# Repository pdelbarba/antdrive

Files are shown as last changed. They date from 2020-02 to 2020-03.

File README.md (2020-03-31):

# Antdrive
Magnettic loop antenna driver arduino shield for amateur radio HF

## Notes
Only one limit switch is pinned out as my setup limits torque such that the capacitor cannot be damaged on the other end. If using standard ethernet cable, you have another two lines (one twisted pair) that can be used for additional switches and signaling however.  I may add this at some point but I'm currently focused on other projects.

## Parts

Designed for the Pololu #1208 stepper motor (https://www.pololu.com/product/1208).  While only rated for 10V it has no issues running at >15v for tuning as the Arduino sketch keeps the motor powered off when not rotating to minimize EMI.  The mounting hardware I used is also available from Pololu.

The motor driver module is an A4988 based board also from Pololu (https://www.pololu.com/product/1182).  In theory it should be able to handle much larger stepper motors, 2A per phase and 35V.

Misc drive hardware is as follows:

https://www.amazon.com/gp/product/B07RXJ5GVG/  Drive side pulley

https://www.amazon.com/gp/product/B07W5L6G8L/  Capacitor side pulley

https://www.amazon.com/gp/product/B07KK86NYX/  Note: I've found these belts to be free of metalic strapping which is important for preventing arcing between the capacitor and the motor

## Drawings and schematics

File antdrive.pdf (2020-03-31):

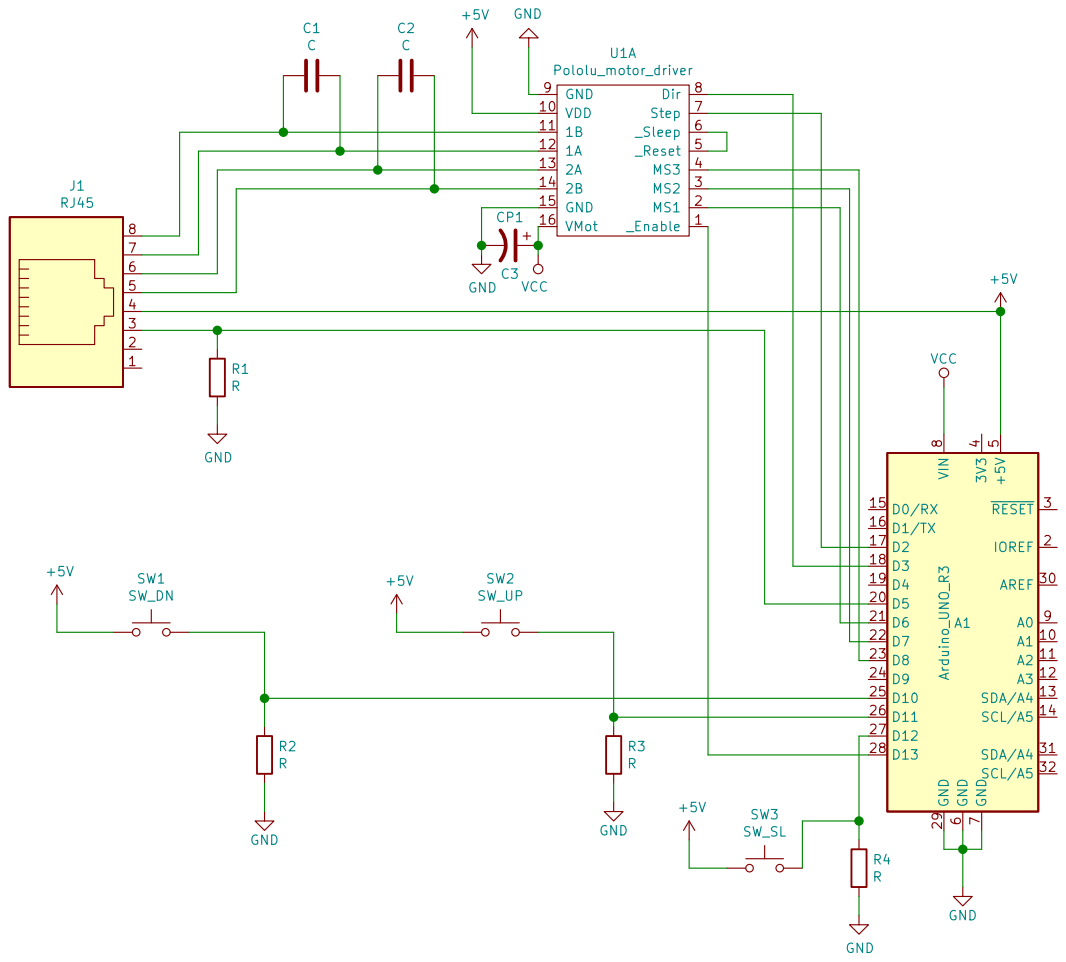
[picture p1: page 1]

Id: 1/1 Title: File: antdrive.sch Sheet: / 12345678

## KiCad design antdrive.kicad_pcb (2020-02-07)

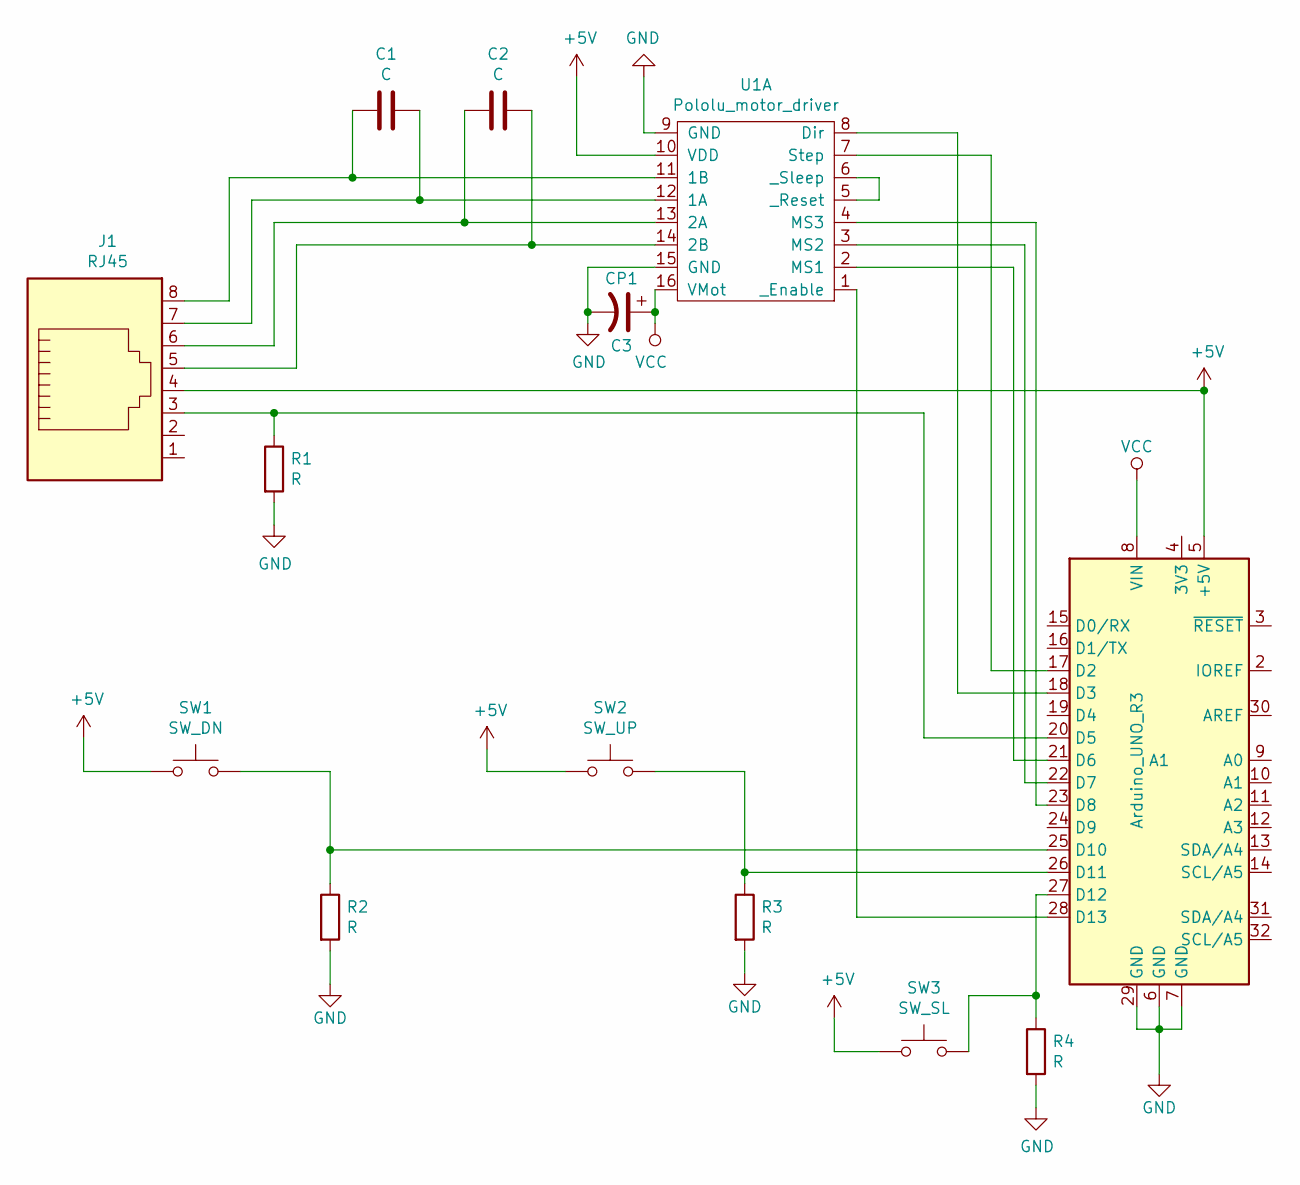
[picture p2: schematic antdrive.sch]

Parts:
A1: Arduino_UNO_R3
C1, C2: C; C_Disc_D5.0mm_W2.5mm_P5.00mm
C3: CP1; CP_Radial_D6.3mm_P2.50mm
J1: RJ45; RJ45_Amphenol_54602-x08_Horizontal
R1, R2, R3, R4: R; R_Axial_DIN0207_L6.3mm_D2.5mm_P10.16mm_Horizontal
SW1: SW_DN; SW_PUSH-12mm
SW2: SW_UP; SW_PUSH-12mm
SW3: SW_SL; SW_PUSH-12mm
U1: Pololu_motor_driver; Pololu_Breakout-16_15.2x20.3mm

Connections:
+5V: A1.5 (+5V), J1.4, SW1.1, SW2.1, SW3.1, U1.10 (VDD)
GND: A1.6 (GND), A1.7 (GND), A1.29 (GND), C3.2, R1.2, R2.2, R3.2, R4.2, U1.9 (GND), U1.15 (GND)
unnamed: A1.17 (D2), U1.7 (Step)
unnamed: A1.18 (D3), U1.8 (Dir)
unnamed: A1.20 (D5), J1.3, R1.1
unnamed: A1.21 (D6), U1.2 (MS1)
unnamed: A1.22 (D7), U1.3 (MS2)
unnamed: A1.23 (D8), U1.4 (MS3)
unnamed: A1.25 (D10), R2.1, SW1.2
unnamed: A1.26 (D11), R3.1, SW2.2
unnamed: A1.27 (D12), R4.1, SW3.2
unnamed: A1.28 (D13), U1.1 (_Enable)
unnamed: C1.1, J1.7, U1.12 (1A)
unnamed: C1.2, J1.8, U1.11 (1B)
unnamed: C2.1, J1.5, U1.14 (2B)
unnamed: C2.2, J1.6, U1.13 (2A)
unnamed: U1.5 (_Reset), U1.6 (_Sleep)
VCC: A1.8 (VIN), C3.1, U1.16 (VMot)

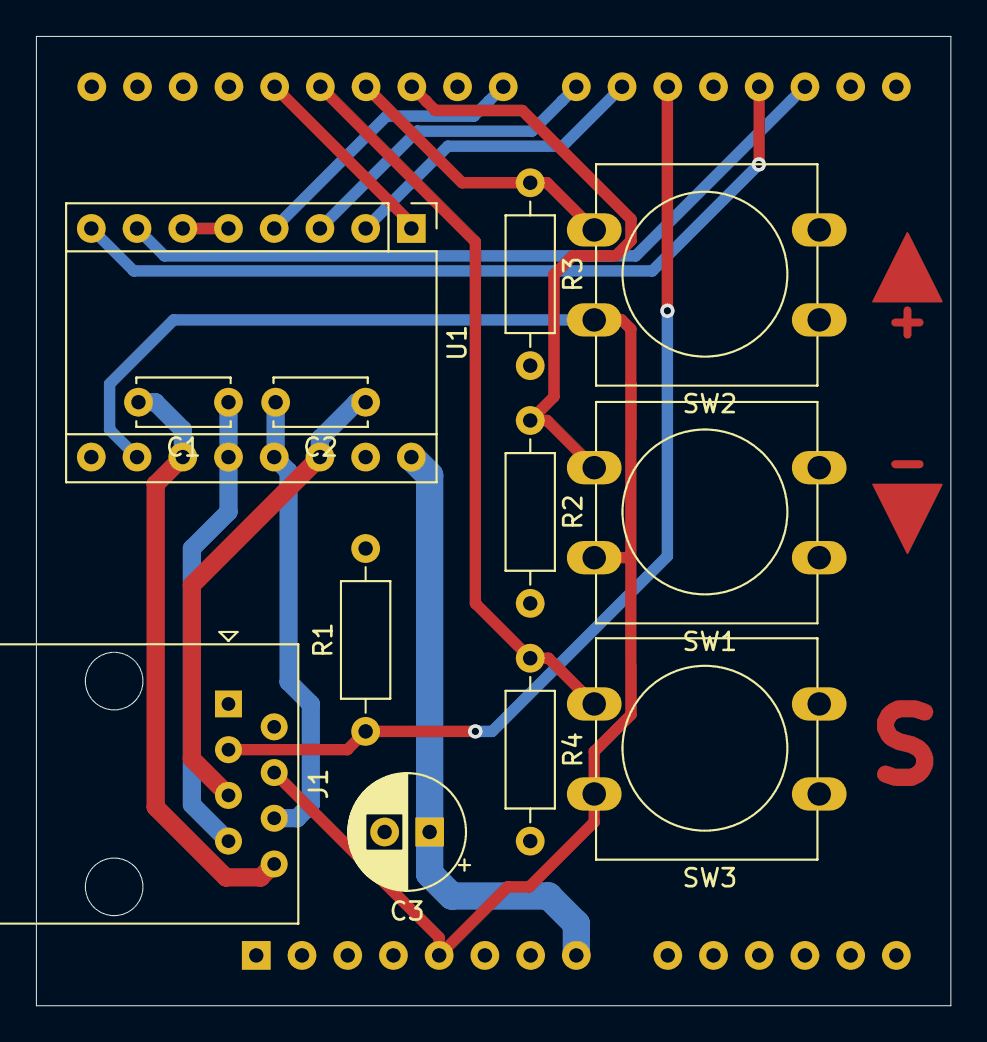
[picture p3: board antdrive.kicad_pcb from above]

Board: 2 copper layers, 50.8 x 53.8 mm, 13 parts (1 on the bottom side), 18 nets.

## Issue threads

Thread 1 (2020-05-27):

soldered and assembled and working intermittently

vo1pwf, 2020-05-27:
made a video to showcase it....
https://youtu.be/UgZoIjrCi4c

up and down buttons dont always work in the same direction....multiple presses of the same button can make it go in different direction.
and the slow step just seems to go in one direction then back again

not sure if you ever ran into that issue before

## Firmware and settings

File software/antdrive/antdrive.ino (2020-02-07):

int stp = 2;
int dir = 3;
int top = 5;
int up = 10;
int dn = 11;
int slo = 12;
int en = 13;

void setup() {
  pinMode(stp, OUTPUT);
  pinMode(dir, OUTPUT);
  pinMode(en, OUTPUT);
  pinMode(up, INPUT);
  pinMode(dn, INPUT);
  pinMode(slo, INPUT);
  pinMode(top, INPUT);
}

void loop() {
  if (digitalRead(up) == HIGH && digitalRead(top) == LOW) {
    digitalWrite(en, LOW);
    digitalWrite(dir, HIGH);
    digitalWrite(stp, HIGH);
    delay(1);
    digitalWrite(stp, LOW);
  } else if (digitalRead(dn) == HIGH) {
    digitalWrite(en, LOW);
    digitalWrite(dir, LOW);
    digitalWrite(stp, HIGH);
    delay(1);
    digitalWrite(stp, LOW);
  } else {
    digitalWrite(en, HIGH);
  }
  if (digitalRead(slo) == HIGH) {
    delay(10);
  }
}

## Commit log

2020-02-07 adds project files
    [antdrive.kicad_pcb, antdrive.sch]
2020-03-31 Adds hardware docs to readme, schematic pdf
